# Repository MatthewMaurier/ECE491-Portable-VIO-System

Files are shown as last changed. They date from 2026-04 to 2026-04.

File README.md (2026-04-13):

## Project Files and Setup

This folder contains all files modified from a clean installation of **ROS1** and **OpenVINS** on a **Raspberry Pi 4** for this project.

### File Locations

Place the files in the following locations:

- **`hardware_init.sh`**  
  Add this to `~/.bashrc` so it runs on startup.

- **`start_vins.sh`**  
  Place this in `~/`

- **`testapp/`**  
  Place this in `~/src/roboeye/`

- **`open_vins/`** and **`camera_ros/`**  
  Place these in `~/catkin_ws/`

- **`ism330publisher.py`**  
  Place this in `~/src/`

- **`capstone desktop app/`**  
  Place this on the desktop of the local machine.

### Additional Project Files

Also included are:

- **Altium source files** in a `.zip` archive
- **Enclosure design file** in `.f3z` format

### Calibration

To calibrate the device, refer to the folder named **`Calibration`**.

### Usage

To use the device in its current state, read **`Quick Start Guide.pdf`**.

### Notes

With these files placed in the correct locations, the project should run on any **Raspberry Pi 4** with **ROS1** and **OpenVINS** installed.

**Contribution:** Everybody

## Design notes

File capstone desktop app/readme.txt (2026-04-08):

1.) install dependencies if not already installed

python -m venv .venv
.venv\Scripts\activate
python -m pip install --upgrade pip
python -m pip install -r requirements_vio_path_viewer.txt

2.) Run the app.bat file

3.) select CSV file downloaded from device.

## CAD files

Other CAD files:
Enclosure v4.f3z

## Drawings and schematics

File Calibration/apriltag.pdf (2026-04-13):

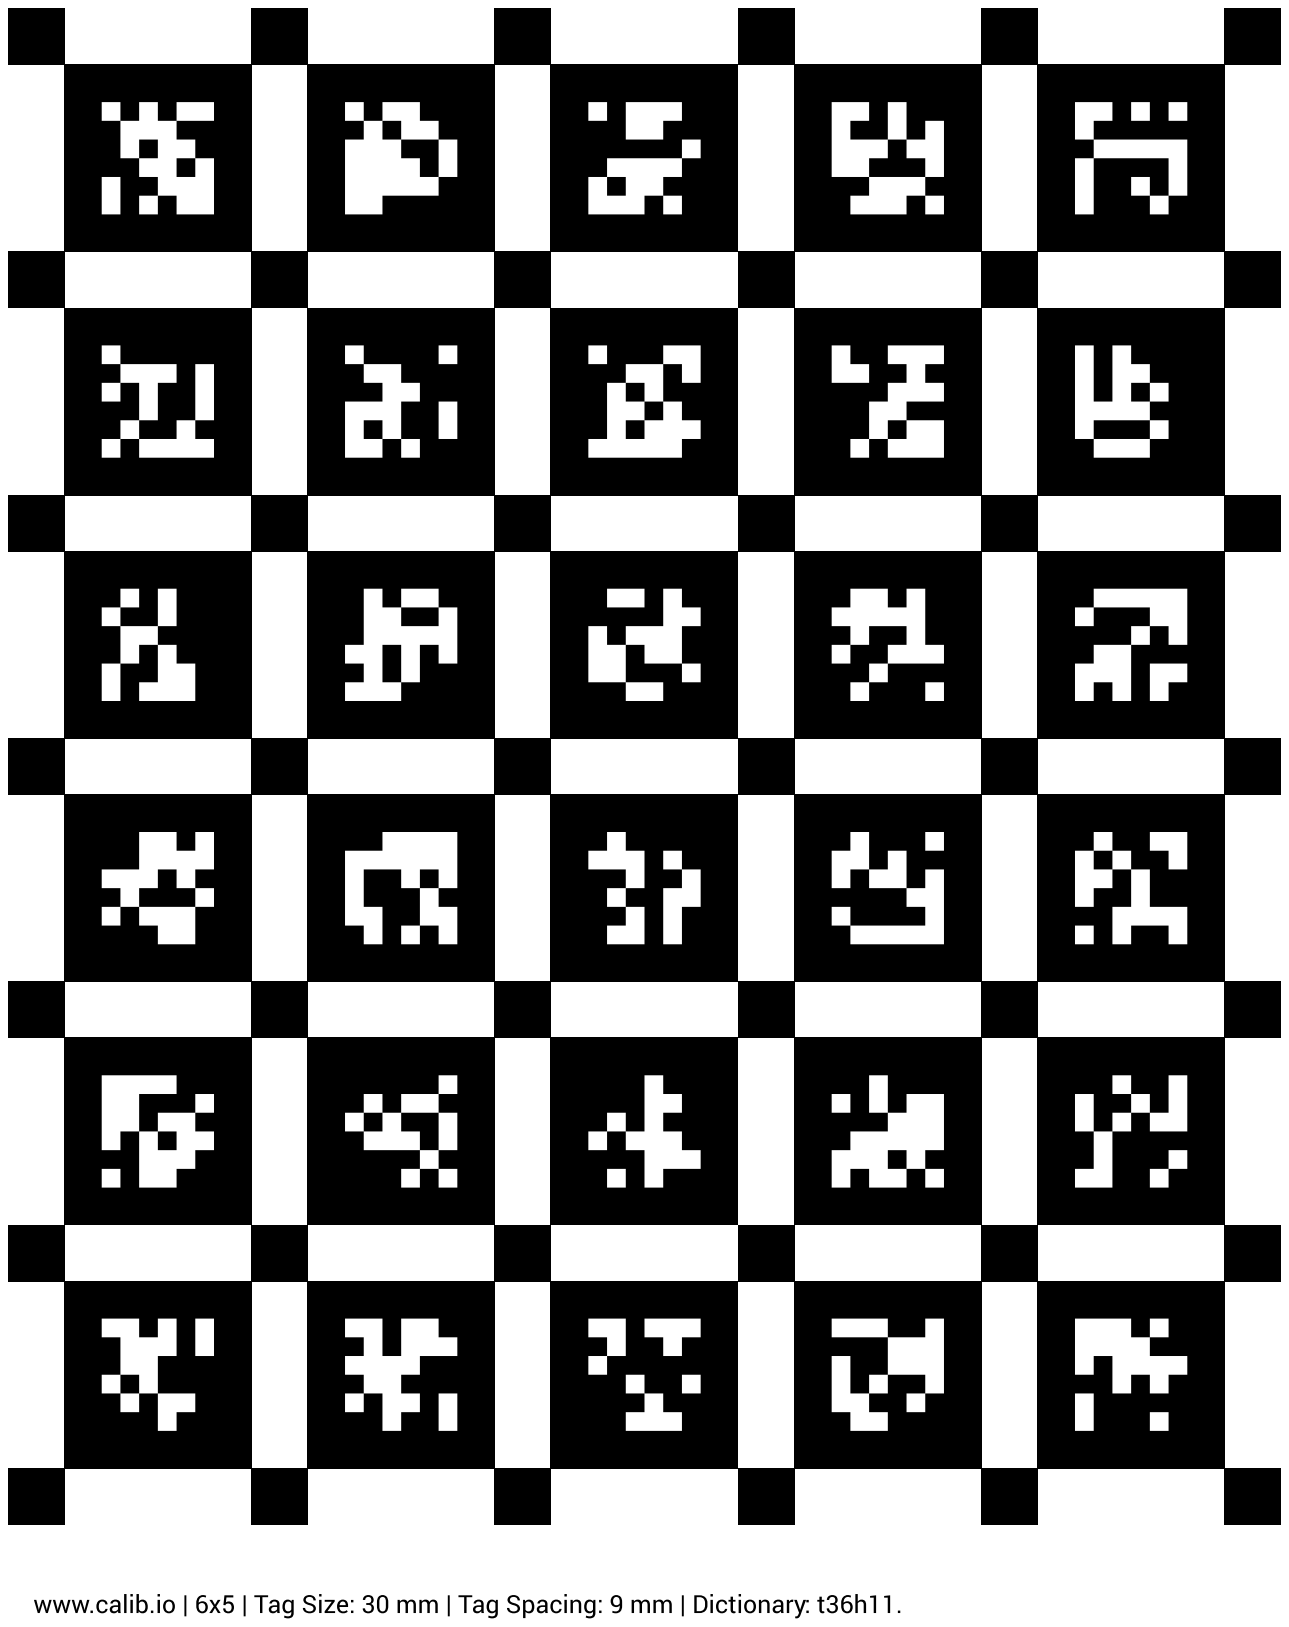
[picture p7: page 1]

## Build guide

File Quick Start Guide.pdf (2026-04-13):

ECE 491 Grp12 VIO Camera
Quick start guide.
i) The device powers on as soon as it receives USB power. There is a USB_C cable in the compartment at the bottom of the device. Once a 5V3A (minimum) battery bank is plugged into this USB C cable, the device will power on

ii) give the device about 30 seconds to power on, and into the Local UI.

iii) in order to access the Web UI, the device must be connected to the same WiFi network as the device you wish to access the WebUI on. To access the menu to change wifi networks, attached a USB keyboard and mouse to the debug USB dongle and the left side of the device, press Alt F4 to close the Local UI, and navigate to the bottom left of the hotbar, where the wifi configuration will be accessible. Once the wifi network is connected, restart the device.

iv) Once the device is on the correct wifi network, the Web UI can be accessed by navigating to the URL shown on the top right of the local UI (should be 192.168.50.X:5000, or a similar local IP address on port 5000).

v) To begin the tracking process, the user can press the start VINS button on the top right of the device. This will open a terminal window on the PI, once that terminal window begins alternating blue and orange text, the device can be initialized by picking it up at a constant speed directly upwards. This initialization process needs to be done at a specific speed. Too slow or too fast and the initialization will fail and the device will begin drifting. It might be necessary to try a few different times to get the speed consistent.

vi) Once features are tracking, logging can be started by pressing the “start logging” button which will record your pose until you hit the “stop logging” button. These logs can be accessed via the web UI by hitting the “view all logs” button on the top right corner of the UI.

vii) it is important to note the two failure states of the device:
1.) Incorrect initialization, will cause drifting immediately
2.) Feature count = 0, if visible features drop to 0, the device will begin drifting in an unrecoverable way. To avoid this, do not point the device at ceilings, blank walls, or lights.

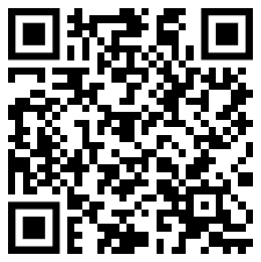
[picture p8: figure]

Project source code and calibration guide available on github here (https://github.com/MatthewMaurier/ECE491-Portable-VIO-System)

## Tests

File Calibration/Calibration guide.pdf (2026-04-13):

Calibration of the device is done using kalibr (https://github.com/ethz-asl/kalibr)

It is recommended that you install Kalibr on a desktop pc inside of WSL, on Ubuntu 20.04.

Once this WSL environment is setup, follow the instructions on the Kalibr github linked above to install kalibr on your device.

To calibrate the device, you will need to plug in a keyboard and mouse to the device, alt-F4 out of the UI and launch two new terminals. Leave all other terminals running.

First, start the IMU. this is done by running

python3 ism330publsiher.py

In the terminal

Next prepare your environment, place the apriltag (in the source codes as apriltag.pdf) on a blank table.

Then hold the device facing downwards at the april tag approximately 3 feet above.

Begin recording a rosbag.

This is done by running

cd ~
rosbag record -o kalibr_run /camera/image_raw /imu0

In the terminal.

This begins by recording a rosbag of the camera and imu data.

Follow this procedure to generate a high quality calibration.

1.

Begin recording

2.

Stillness (10–15 s)

Hold the camera still

Pointing straight down at the grid

This helps estimate IMU biases

3.

Rotations (MOST IMPORTANT)
Keep the grid visible and rotate the camera: Roll
Twist the camera clockwise / counterclockwise (like turning a doorknob)
Pitch
Tilt forward/backward
(top of camera closer/farther from the table) Yaw
Rotate left/right
(spin around vertical axis)

4.

Phase C — Translation

Still pointing at the board: Move closer / farther
Slide left / right
Slide forward / backward

5.

Phase D — Combined motion
Gentle figure-8s
Rotate while translating
Change distance + angle

When finished, press crtl+c in the terminal to stop recording. The video should be about 2 minutes long,

And will save in home/vin as kalibr_run.bag

Next, transfer this file to the PC with kalibr installed using either cloud upload or a usb stick.

Place it somewhere easy to navigate to in a terminal, I used a folder directly on the c drive called “cap”. In it, also place the imu.yaml and aprilgrid.yaml files in the calibration folder.

To generate the calibration, follow the follow steps, with the file name you chose in place of kalibr_run

execute:
cd mnt/c/cap

2.

execute:
export KALIBR_MANUAL_FOCAL_LENGTH_INIT=1

execute:
kalibr_calibrate_cameras \
--bag kalibr_run.bag \
--topics /cam0/image_raw \
--models pinhole-radtan \
--target aprilgrid.yaml

when prompted for focal length. enter 400 3.

execute:
cd /mnt/c/cap

execute:
kalibr_calibrate_imu_camera \ --bag kalibr_run.bag \
--cam kalibr_run-camchain.yaml \ --imu imu.yaml \
--target aprilgrid.yaml
4

This will generate many files in the root folder, but the important one is the one ending with camchain-imuchain.yaml. This is where the IMU-Camera translation matrix, and camera distortion matrices are found.

To use this calibration, navigate to the openvins install config directory on the device (home/vin/catkin_ws/openvins/config/euroc_mav) and replace the values in the current imucam file with the values in the generated file. The format is the same, but indentation is strict, so it is best not to copy the entire text file.

This should calibrate the device.

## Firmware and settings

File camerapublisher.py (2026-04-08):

#!/usr/bin/env python3
import rospy
from sensor_msgs.msg import Image
from cv_bridge import CvBridge
import cv2
import numpy as np

class MonoRepublisher:
    def __init__(self):
        self.bridge = CvBridge()
        in_topic  = rospy.get_param("~in",  "/libcamera_ros/image_raw")
        out_topic = rospy.get_param("~out", "/cam0/image_raw")

        self.pub = rospy.Publisher(out_topic, Image, queue_size=1)
        self.sub = rospy.Subscriber(in_topic, Image, self.cb, queue_size=1)

    def cb(self, msg: Image):
        enc = msg.encoding.lower()

        # Common case: RGB/BGR already decoded
        if enc in ["bgr8", "rgb8"]:
			
            cv_img = self.bridge.imgmsg_to_cv2(msg, desired_encoding=enc)
            
            mono = cv2.cvtColor(cv_img, cv2.COLOR_BGR2GRAY) if enc == "bgr8" else cv2.cvtColor(cv_img, cv2.COLOR_RGB2GRAY)
            
            out = self.bridge.cv2_to_imgmsg(mono, encoding="mono8")
            out.header = msg.header
            
            self.pub.publish(out)
            return

        # If your driver publishes yuv420 in one buffer, you can take the Y plane.
        # For yuv420p: first width*height bytes are Y.
        if "yuv420" in enc:
			
            w, h = msg.width, msg.height
            print("yuv420")
            data = np.frombuffer(msg.data, dtype=np.uint8)
            y = data[:w*h].reshape((h, w))  # luma
            out = self.bridge.cv2_to_imgmsg(y, encoding="mono8")
            out.header = msg.header
            self.pub.publish(out)
            return

        rospy.logwarn_throttle(5.0, f"Unsupported encoding for mono conversion: {msg.encoding}")

if __name__ == "__main__":
    rospy.init_node("mono_republisher")
    MonoRepublisher()
    rospy.spin()

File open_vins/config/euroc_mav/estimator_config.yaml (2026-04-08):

%YAML:1.0 # need to specify the file type at the top!

verbosity: "INFO" # ALL, DEBUG, INFO, WARNING, ERROR, SILENT

use_fej: true # if first-estimate Jacobians should be used (enable for good consistency)
integration: "rk4" # discrete, rk4, analytical (if rk4 or analytical used then analytical covariance propagation is used)
use_stereo: true # NEED TO USE STEREO! OTHERWISE CAN'T RECOVER SCALE!!!!!! DEGENERATE MOTION!!!
max_cameras: 1 # NEED TO USE STEREO! OTHERWISE CAN'T RECOVER SCALE!!!!!! DEGENERATE MOTION!!!

calib_cam_extrinsics: false # disable since this is a degenerate motion
calib_cam_intrinsics: false
calib_cam_timeoffset: true # disable since this is a degenerate motion
calib_imu_intrinsics: false
calib_imu_g_sensitivity: false

max_clones: 11 # how many clones in the sliding window
max_slam: 50 # number of features in our state vector
max_slam_in_update: 25 # update can be split into sequential updates of batches, how many in a batch
max_msckf_in_update: 50 # how many MSCKF features to use in the update
dt_slam_delay: 1 # delay before initializing (helps with stability from bad initialization...)

gravity_mag: 9.81 # magnitude of gravity in this location

feat_rep_msckf: "ANCHORED_MSCKF_INVERSE_DEPTH"
feat_rep_slam: "ANCHORED_MSCKF_INVERSE_DEPTH"
feat_rep_aruco: "ANCHORED_MSCKF_INVERSE_DEPTH"

# zero velocity update parameters we can use
# we support either IMU-based or disparity detection.
try_zupt: false
zupt_chi2_multipler: 0.02 # set to 0 for only disp-based
zupt_max_velocity: 0.02
zupt_noise_multiplier: 10
zupt_max_disparity: 0 # set to 0 for only imu-based
zupt_only_at_beginning: false

# ==================================================================
# ==================================================================

init_window_time: 2.0 # how many seconds to collect initialization information
init_imu_thresh: 0.20 # threshold for variance of the accelerometer to detect a "jerk" in motion
init_max_disparity: 5.0 # max disparity to consider the platform stationary (dependent on resolution)
init_max_features: 50 # how many features to track during initialization (saves on computation)

init_dyn_use: false
init_dyn_mle_opt_calib: false
init_dyn_mle_max_iter: 50
init_dyn_mle_max_time: 0.05
init_dyn_mle_max_threads: 6
init_dyn_num_pose: 6
init_dyn_min_deg: 5.0

init_dyn_inflation_ori: 10
init_dyn_inflation_vel: 100
init_dyn_inflation_bg: 10
init_dyn_inflation_ba: 100
init_dyn_min_rec_cond: 1e-15

init_dyn_bias_g: [0.0, 0.0, 0.0]
init_dyn_bias_a: [0.0, 0.0, 0.0]

# ==================================================================
# ==================================================================

record_timing_information: false # if we want to record timing information of the method
record_timing_filepath: "/tmp/traj_timing.txt" # https://docs.openvins.com/eval-timing.html#eval-ov-timing-flame

# if we want to save the simulation state and its diagional covariance
# use this with rosrun ov_eval error_simulation
save_total_state: false
filepath_est: "/tmp/ov_estimate.txt"
filepath_std: "/tmp/ov_estimate_std.txt"
filepath_gt: "/tmp/ov_groundtruth.txt"

# ==================================================================
# ==================================================================

# our front-end feature tracking parameters
# we have a KLT and descriptor based (KLT is better implemented...)
use_klt: true
num_pts: 500
fast_threshold: 20
grid_x: 20
grid_y: 20
min_px_dist: 10
knn_ratio: 0.70
track_frequency: 30.0
downsample_cameras: true # will downsample image in half if true
num_opencv_threads: 4 # -1: auto, 0-1: serial, >1: number of threads
histogram_method: "NONE" # NONE, HISTOGRAM, CLAHE

fi_max_dist: 10.0
fi_max_baseline: 200
fi_max_cond_number: 25000

# aruco tag tracker for the system
# DICT_6X6_1000 from https://chev.me/arucogen/
use_aruco: false
num_aruco: 1024
downsize_aruco: true

# ==================================================================
# ==================================================================

# camera noises and chi-squared threshold multipliers
up_msckf_sigma_px: 1.2
up_msckf_chi2_multipler: 1
up_slam_sigma_px: 1.2
up_slam_chi2_multipler: 1
up_aruco_sigma_px: 1
up_aruco_chi2_multipler: 1

# masks for our images
use_mask: false

# imu and camera spacial-temporal
# imu config should also have the correct noise values
relative_config_imu: "kalibr_imu_chain.yaml"
relative_config_imucam: "kalibr_imucam_chain.yaml"

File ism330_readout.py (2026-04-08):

import time
import board

from adafruit_lsm6ds.ism330dhcx import ISM330DHCX

# Create I2C bus using the default SCL/SDA pins (/dev/i2c-1 on Pi)
i2c = board.I2C()  # uses board.SCL and board.SDA

# Optional: debug scan to prove we see 0x6A
while not i2c.try_lock():
    pass
print("Found I2C addresses:", [hex(x) for x in i2c.scan()])
i2c.unlock()

# Create sensor object at 0x6A (what i2cdetect showed)
sensor = ISM330DHCX(i2c, address=0x6A)

print("ISM330DHCX initialized OK, reading values...\n")

while True:
    ax, ay, az = sensor.acceleration   # m/s^2
    gx, gy, gz = sensor.gyro           # rad/s

    print(
        f"Accel: X={ax:6.2f} Y={ay:6.2f} Z={az:6.2f} m/s^2  |  "
        f"Gyro: X={gx:6.2f} Y={gy:6.2f} Z={gz:6.2f} rad/s"
    )
    time.sleep(0.02)

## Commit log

2026-04-08 big commit
    [MH_04_difficult.csv, MH_05_difficult.csv, V1_01_easy.csv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]
2026-04-08 capstone desktop app
    [line.csv, vio_pose_20260401_155654.csv, vio_pose_20260401_160528.csv]
2026-04-13 final commit (I think)
    [Enclosure v4.f3z]
